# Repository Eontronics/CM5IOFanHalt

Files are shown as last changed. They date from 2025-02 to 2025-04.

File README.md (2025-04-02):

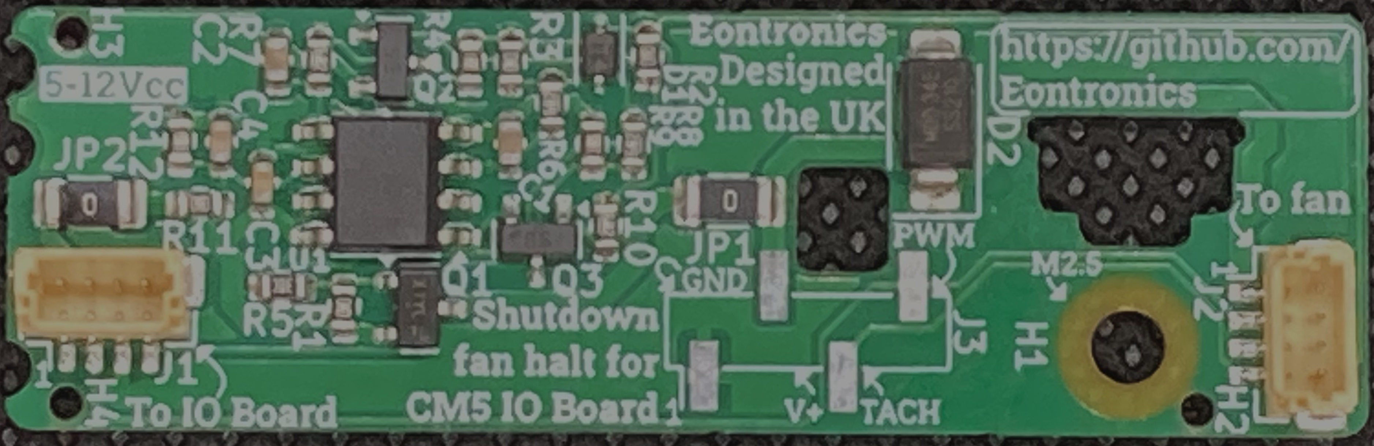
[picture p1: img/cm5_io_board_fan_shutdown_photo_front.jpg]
PCB front render


# CM5 IO Board Fan Halt
A small, low cost add-on module for the Raspberry Pi Compute Module 5 IO Board to halt the fan from spinning after shutting the Pi down!
Development logs of the hardware can be found on the [Hackaday.io project page](https://hackaday.io/project/202403-cm5-io-board-fan-halt).

## What is it for?
After shutting down the Raspberry Pi Compute module 5, the fan control PWM signal is allowed to float high. 
As a result, the fan ramps up to full speed after turning everything else off, and the only way to stop it is to unplug the power.
Annoying!

This module can be attached directly to the Compute Module 5 IO board, and electrically sits betwween the fan header and the fan.
When it detects the Pi has been shutdown, it also automatically cuts power to the fan to keep it from spinning up and making noise.

## How does it work?
The module monitors the voltage on he 'CM5_3.3V' rail of the Compute Module 5 to determine whether it is an active or shutdown state.
Conveniently, this rail drives the pullup resistor on the 'Fan_Tacho' pin, so it is possible to monitor it through the fan header.

By monitoring how long it has been since this pin was pulled high, it can detect whether 'CM5_3.3V' is powered, while ignoring brief
'low' pulses that occur when the signal is pulled down through the fan tachometer. This then drives a high side transistor to either
provide or cut power to the fan.

## Show me that it works!
Don't just take my word for it, I've linked a short video [here](https://www.youtube.com/watch?v=HvpnCyq3iTY) to demonstrate that the module does what it's supposed to do!

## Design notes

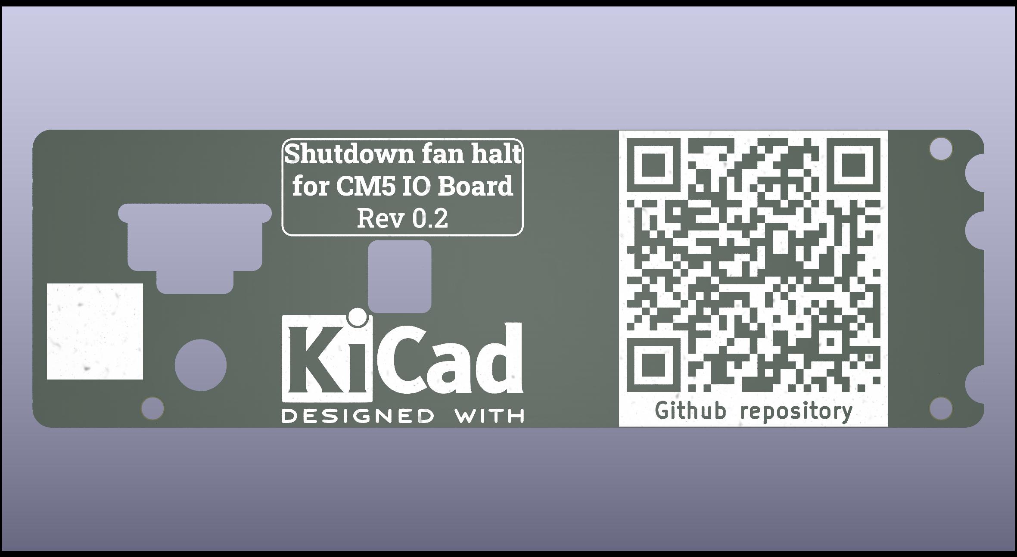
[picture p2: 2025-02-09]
img/cm5_io_board_fan_shutdown_render_back.jpg

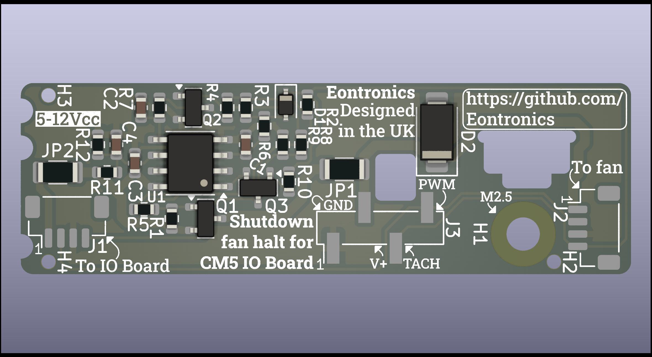
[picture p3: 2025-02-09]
img/cm5_io_board_fan_shutdown_render_front.jpg

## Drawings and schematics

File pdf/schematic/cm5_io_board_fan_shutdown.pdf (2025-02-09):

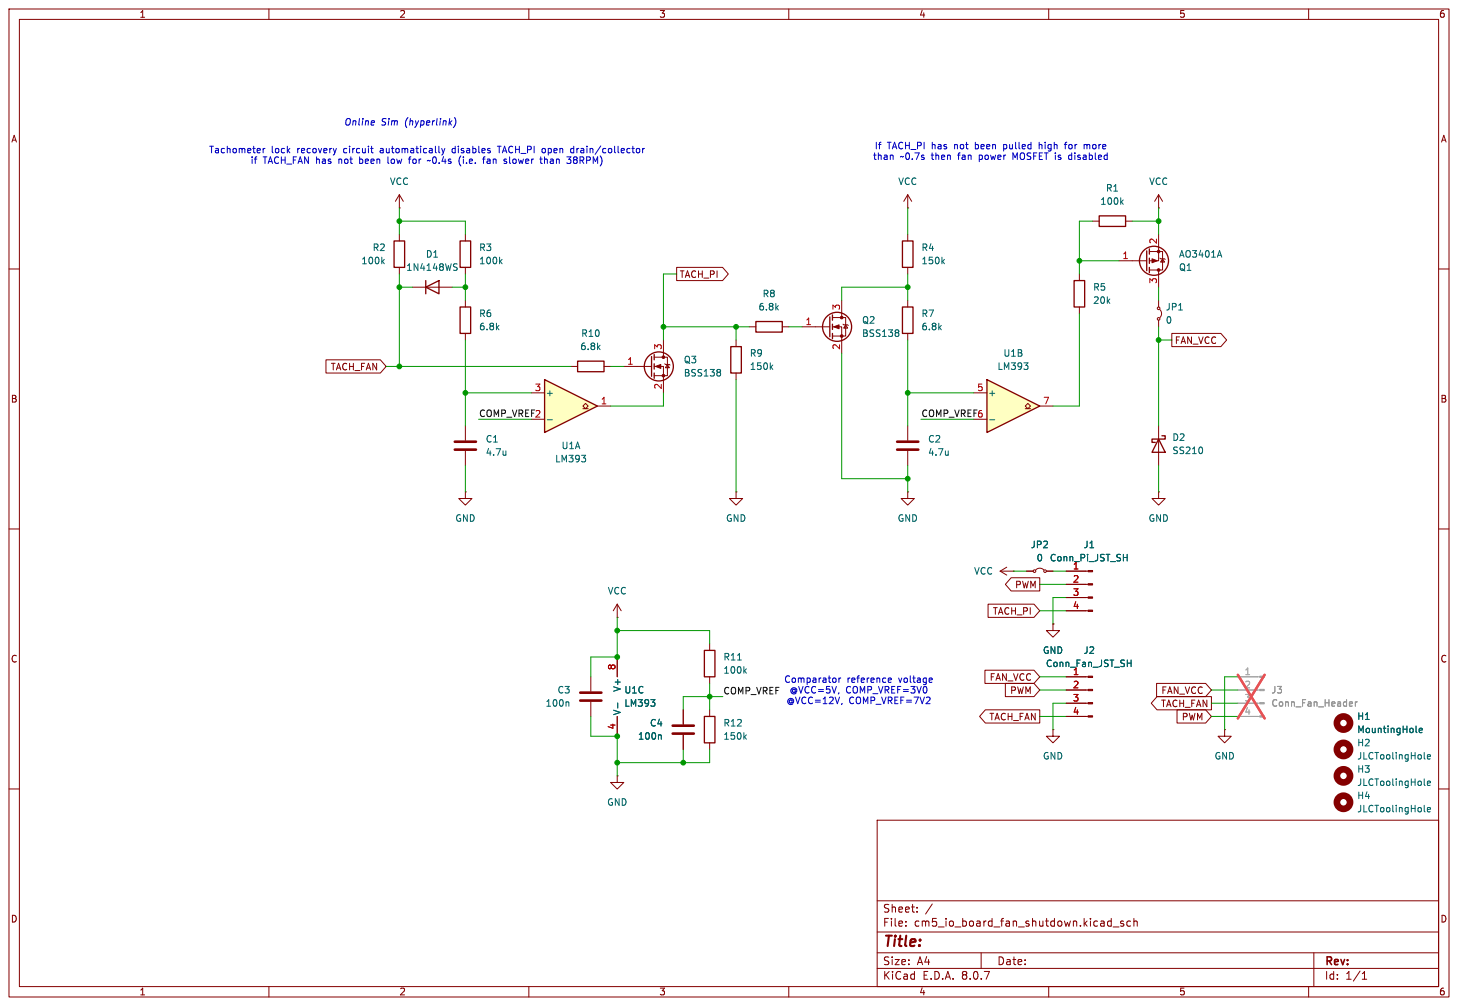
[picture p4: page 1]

If TACH_PI has not been pulled high for more
150k VCC
20k VCC

Id: 1/1 Title: File: cm5_io_board_fan_shutdown.kicad_sch Sheet: /

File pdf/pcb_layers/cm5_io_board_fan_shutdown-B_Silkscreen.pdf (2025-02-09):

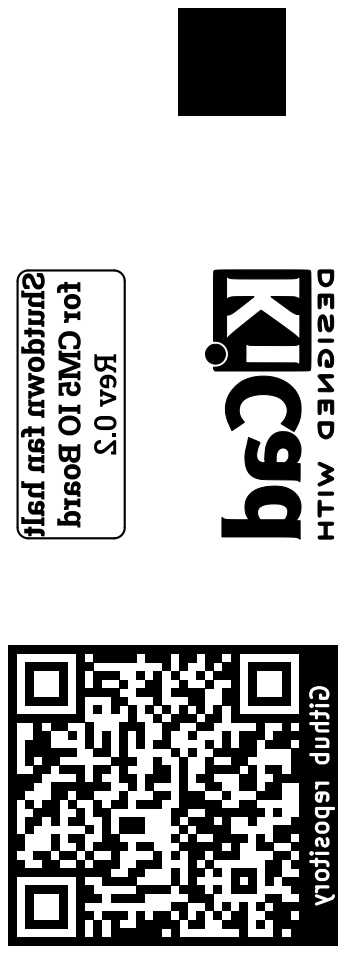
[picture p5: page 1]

Shutdown fan halt for CM5 IO Board Rev 0.2

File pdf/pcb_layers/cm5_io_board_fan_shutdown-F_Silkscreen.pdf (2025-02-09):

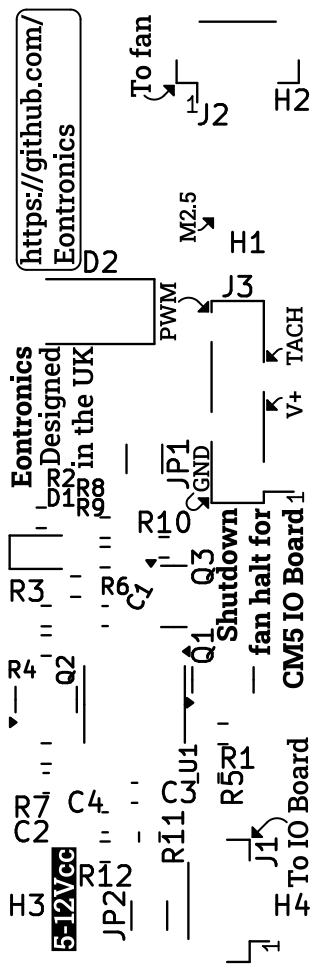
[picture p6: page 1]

1 Designed in the UK To IO Board GND PWM

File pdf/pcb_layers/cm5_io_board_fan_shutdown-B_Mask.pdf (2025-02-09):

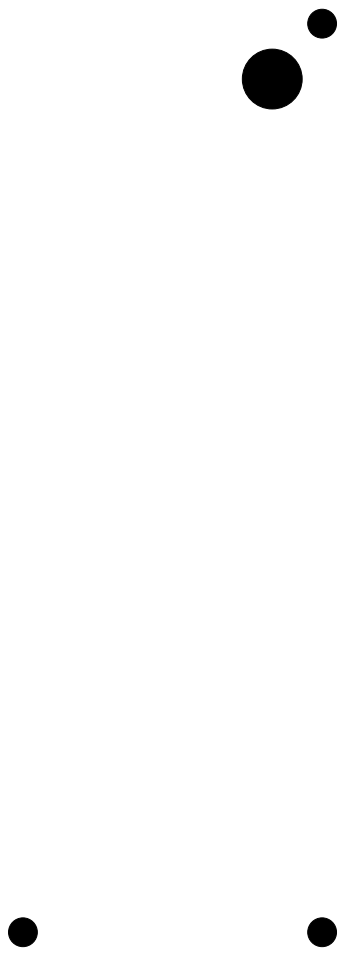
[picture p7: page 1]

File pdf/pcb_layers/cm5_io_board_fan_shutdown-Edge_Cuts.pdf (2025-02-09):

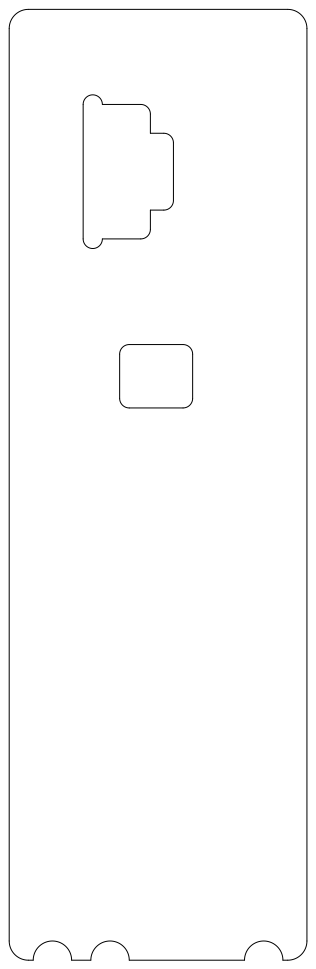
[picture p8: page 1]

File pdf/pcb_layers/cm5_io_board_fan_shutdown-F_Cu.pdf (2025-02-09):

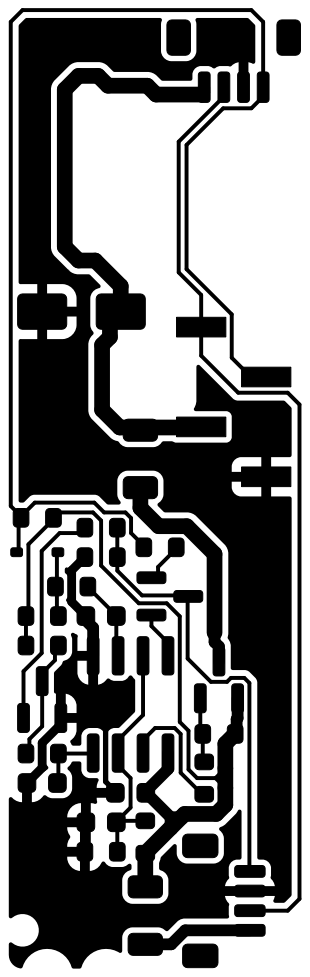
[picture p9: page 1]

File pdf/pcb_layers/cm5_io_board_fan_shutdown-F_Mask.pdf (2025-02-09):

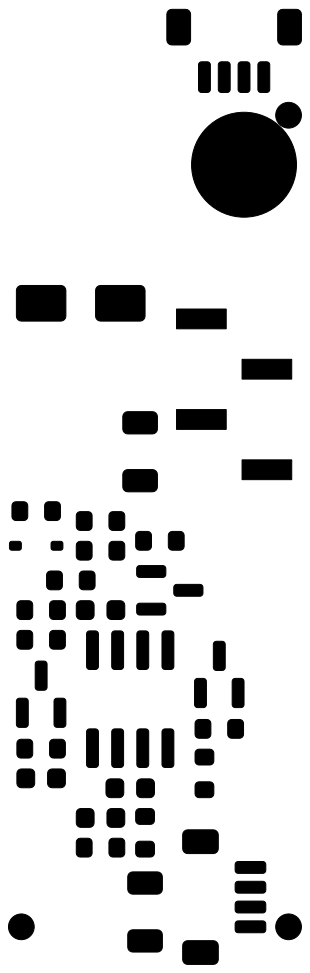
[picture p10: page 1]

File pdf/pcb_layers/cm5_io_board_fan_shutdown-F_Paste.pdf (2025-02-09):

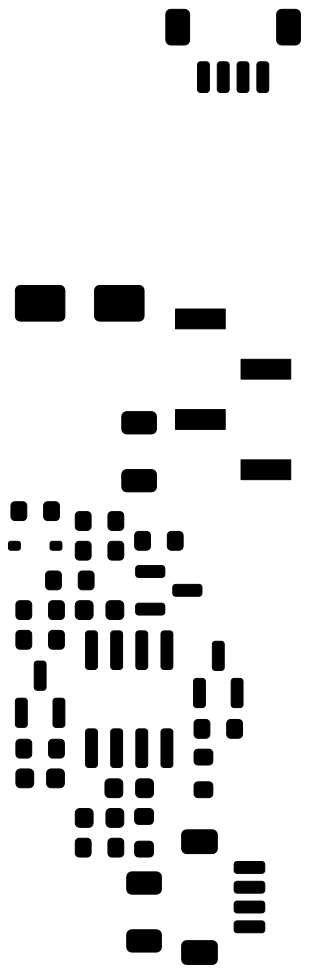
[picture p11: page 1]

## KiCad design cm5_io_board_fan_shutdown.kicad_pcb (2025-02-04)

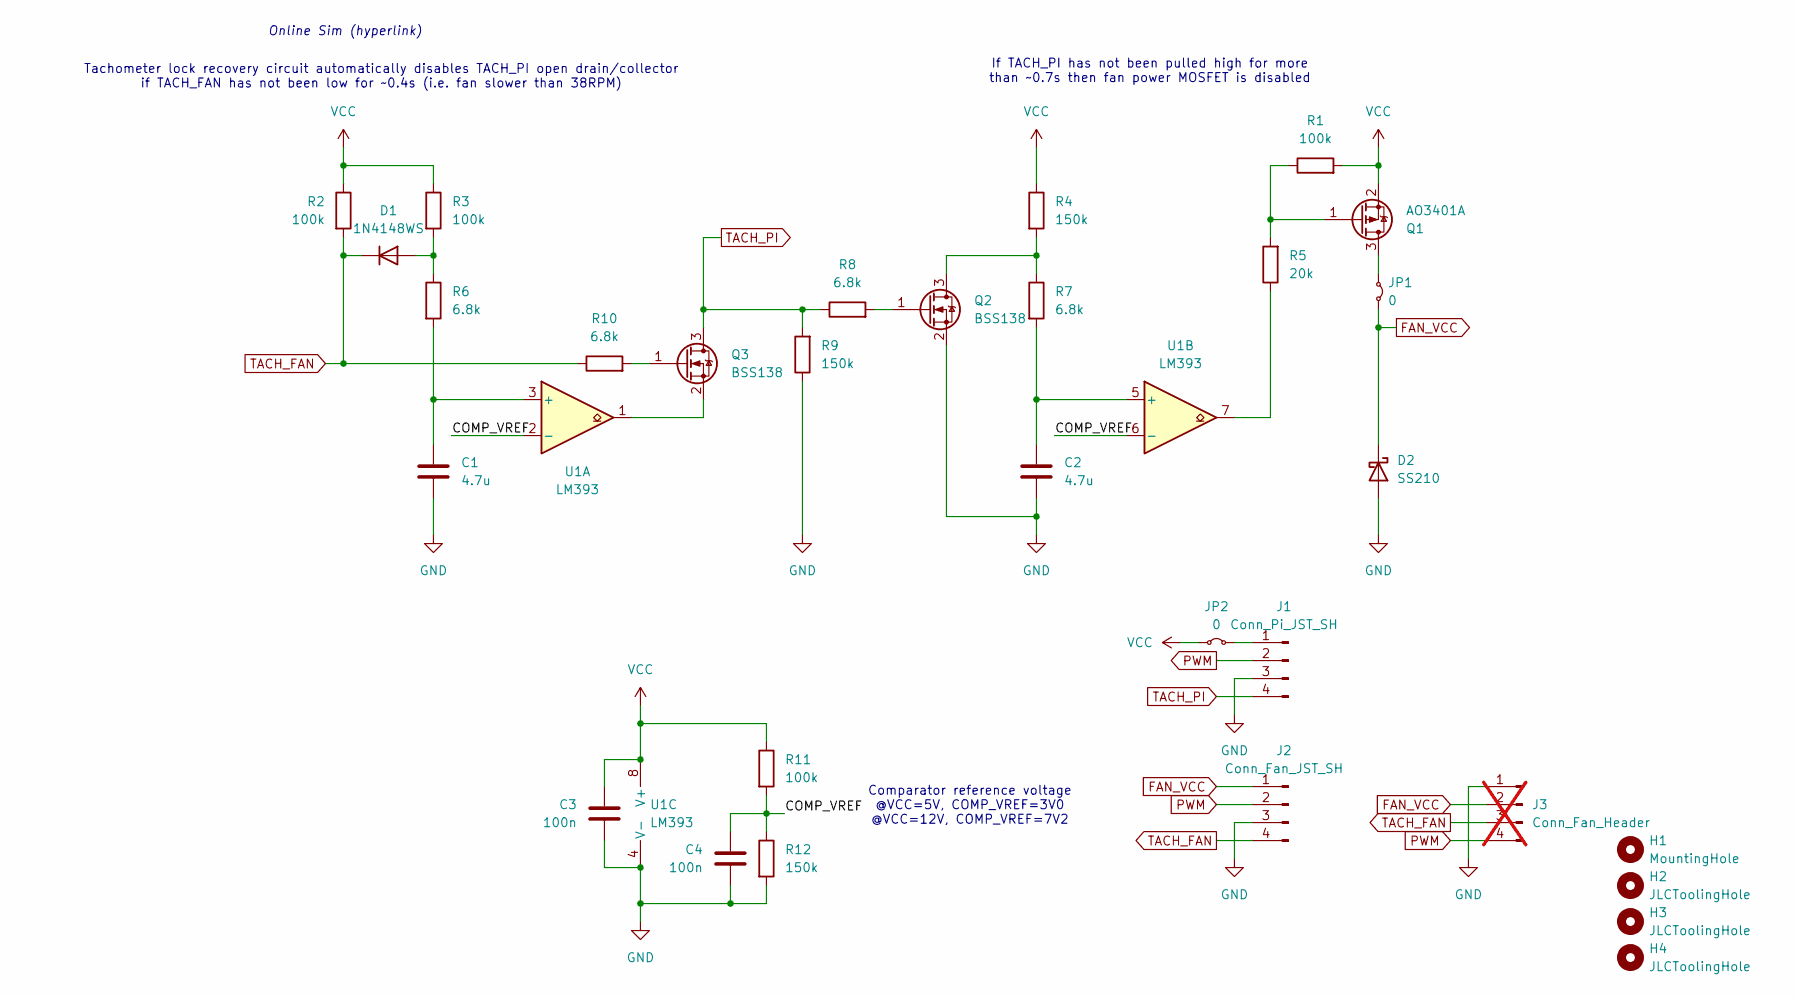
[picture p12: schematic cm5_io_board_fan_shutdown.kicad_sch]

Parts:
C1, C2: 4.7u; C_0603_1608Metric
C3, C4: 100n; C_0603_1608Metric
D1: 1N4148WS; D_SOD-323
D2: SS210; D_SMA
H1: MountingHole; MountingHole_2.7mm_M2.5_DIN965
H2, H3, H4: JLCToolingHole; JLC_Tooling_Hole
J1: Conn_Pi_JST_SH; JST_SH_BM04B-SRSS-TB_1x04-1MP_P1.00mm_Vertical
J2: Conn_Fan_JST_SH; JST_SH_BM04B-SRSS-TB_1x04-1MP_P1.00mm_Vertical
J3: Conn_Fan_Header; PinHeader_1x04_P2.54mm_Vertical_SMD_Pin1Left; not fitted
JP1, JP2: 0; R_1206_3216Metric
Q1: AO3401A; SOT-23
Q2, Q3: BSS138; SOT-23
R1, R2, R3, R11: 100k; R_0603_1608Metric
R4, R9, R12: 150k; R_0603_1608Metric
R5: 20k; R_0603_1608Metric
R6, R7, R8, R10: 6.8k; R_0603_1608Metric
U1: LM393; SOIC-8_3.9x4.9mm_P1.27mm

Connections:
/COMP_VREF: C4.1, R11.2, R12.1, U1.2 (-), U1.6 (-)
FAN_VCC: D2.1 (K), J2.1, J3.2, JP1.2 (B)
GND: C1.2, C2.2, C3.2, C4.2, D2.2 (A), J1.3, J2.3, J3.1, Q2.2 (S), R9.1, R12.2, U1.4 (V-)
unnamed: D1.2 (A), R3.2, R6.1
unnamed: J1.1, JP2.2 (B)
unnamed: JP1.1 (A), Q1.3 (D)
unnamed: Q1.1 (G), R1.1, R5.2
unnamed: Q2.3 (D), R4.2, R7.1
unnamed: Q2.1 (G), R8.2
unnamed: Q3.1 (G), R10.2
unnamed: Q3.2 (S), U1.1
unnamed: R5.1, U1.7
unnamed: C1.1, R6.2, U1.3 (+)
unnamed: C2.1, R7.2, U1.5 (+)
PWM: J1.2, J2.2, J3.4
TACH_FAN: D1.1 (K), J2.4, J3.3, R2.2, R10.1
TACH_PI: J1.4, Q3.3 (D), R8.1, R9.2
VCC: C3.1, JP2.1 (A), Q1.2 (S), R1.2, R2.1, R3.1, R4.1, R11.1, U1.8 (V+)

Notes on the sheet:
Comparator reference voltage @VCC=5V, COMP_VREF=3V0 @VCC=12V, COMP_VREF=7V2
Online Sim (hyperlink)
Tachometer lock recovery circuit automatically disables TACH_PI open drain/collector if TACH_FAN has not been low for ~0.4s (i.e. fan slower than 38RPM)
If TACH_PI has not been pulled high for more than ~0.7s then fan power MOSFET is disabled

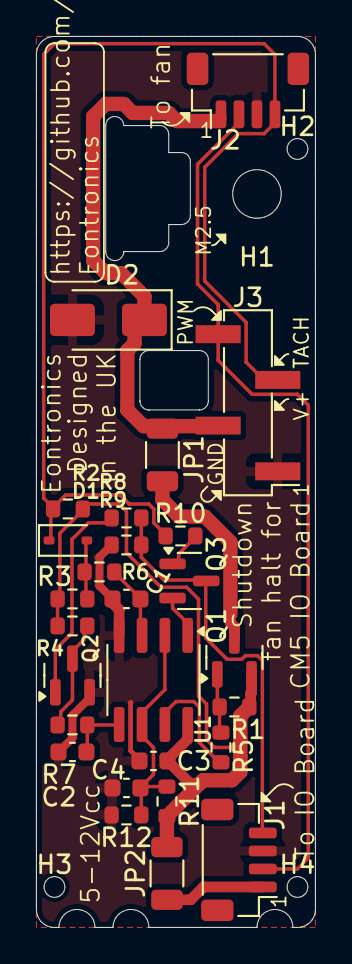
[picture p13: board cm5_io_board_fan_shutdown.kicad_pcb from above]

Board: 2 copper layers, 15.5 x 49.5 mm, 32 parts (1 on the bottom side), 18 nets.

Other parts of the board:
QR*****: GithubQR

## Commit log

2025-02-02 added kicad .lck files to gitignore
2025-02-02 [fix_output_drive] flipped output FET, added voltage divider in output driver schematic
    Output P-FET has been flipped so it should no longer conduct through body diode when off, gate resistor has been changed to form voltage divider with pullup to limit VGS to ~10V when operating from 12Vcc as VGSmax is +-12V
    [cm5_io_board_fan_shutdown.kicad_sch]
2025-02-02 [fix_output_drive] Updated PCB layout to reflect output FET flip in schematic and resistor divider on gate
    [cm5_io_board_fan_shutdown.kicad_pcb]
2025-02-02 [fix_output_drive] Updated silkscreen references to reduce overlapping, adjusted position of text slightly
    [cm5_io_board_fan_shutdown.kicad_pcb]
2025-02-04 [update_to_v0.2] set grid origin point to bottom left corner of PCB
    [cm5_io_board_fan_shutdown.kicad_pcb]
2025-02-04 [update_to_v0.2] updated SOT-23 footprints to match KiCAD library versions
    DRC highlighed SOT-23 footprints did not match version in library, these have been updated to clear DRC error despite appearing visually the same
    [cm5_io_board_fan_shutdown.kicad_pcb]
2025-02-04 [update_to_v0.2] Updated version number in silkscreen to revision 0.2, changed QR code to point to project repo
    [cm5_io_board_fan_shutdown.kicad_pcb]
2025-02-05 Removed .kicad_prl file and added to .gitignore
2025-02-09 Added renders and PDFs of schematic/PCB for viewing without KiCAD
2025-04-02 Added front photo of assembled v0.2 board
2025-04-02 Replaced header image in README.md with PCB photo + links to Hackaday project & demo video
